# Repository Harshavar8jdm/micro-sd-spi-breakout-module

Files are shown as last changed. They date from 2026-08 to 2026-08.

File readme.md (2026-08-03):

# 3.3V MicroSD Card SPI Breakout Board

A compact, high-performance, 2-layer **MicroSD Card Breakout Board** designed in KiCad for embedded microcontrollers using the **SPI (Serial Peripheral Interface)** bus.

Designed specifically for 3.3V native logic ecosystems (STM32, ESP32, RP2040, SAMD, Nordic, etc.), this module provides clean power decoupling, signal pull-ups, and a low-EMI ground plane layout.

---

## Board Renders

| Top View | Bottom View |
| :---: | :---: |
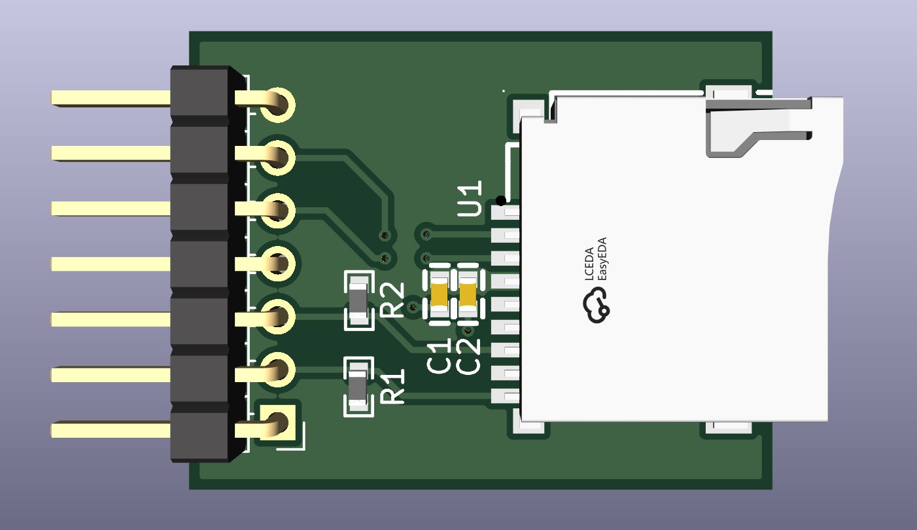
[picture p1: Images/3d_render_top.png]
3D Top Render
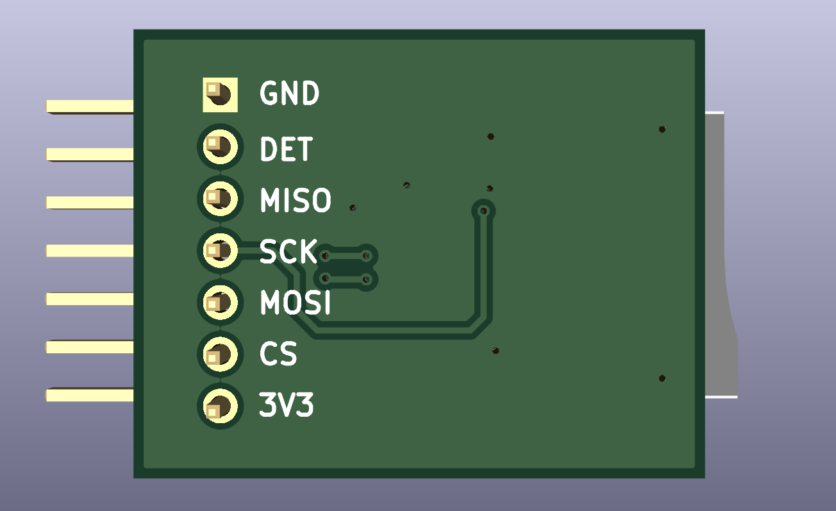
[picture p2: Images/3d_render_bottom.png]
3D Bottom Render
|  |  |

---

## Key Features

* **Native 3.3V Operation:** Designed without slow active/passive level shifters, maximizing SPI bus speeds (up to 25 MHz) with zero signal propagation delay.
* **Transient Power Decoupling:** Dedicated 10 uF bulk ceramic cap (C1) and 100 nF high-frequency ceramic cap (C2) positioned directly adjacent to the SD socket's VDD pin (Pin 4) to handle flash memory write current spikes (up to 200 mA).
* **Bus Stability:** Integrated 10k Ohm pull-up resistors on signal lines to prevent floating inputs and accidental bus writes during microcontroller startup/reset.
* **Card Detection:** Mechanically broken-out Card Detect (CD_DET) line to trigger hardware interrupts on card insertion/removal.
* **Optimized 2-Layer Signal Integrity:** Signal routing optimized for continuous return paths over an unbroken bottom Ground plane, minimizing EMI and clock ringing.
* **Standard 2.54mm Header:** 1x7 pin header footprint for breadboard prototyping or jumper wiring.

---

## Schematic & Layout

### Schematic
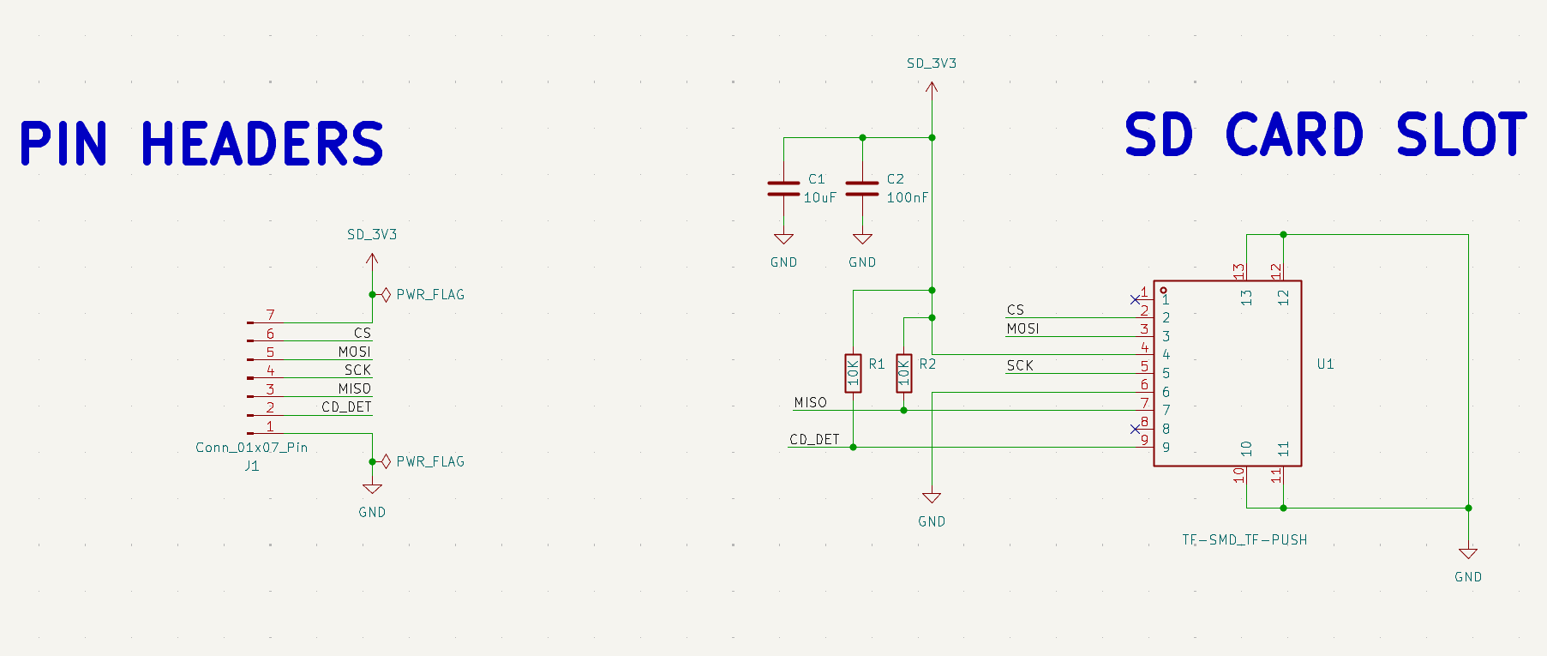
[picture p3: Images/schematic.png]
Schematic


### PCB Layout
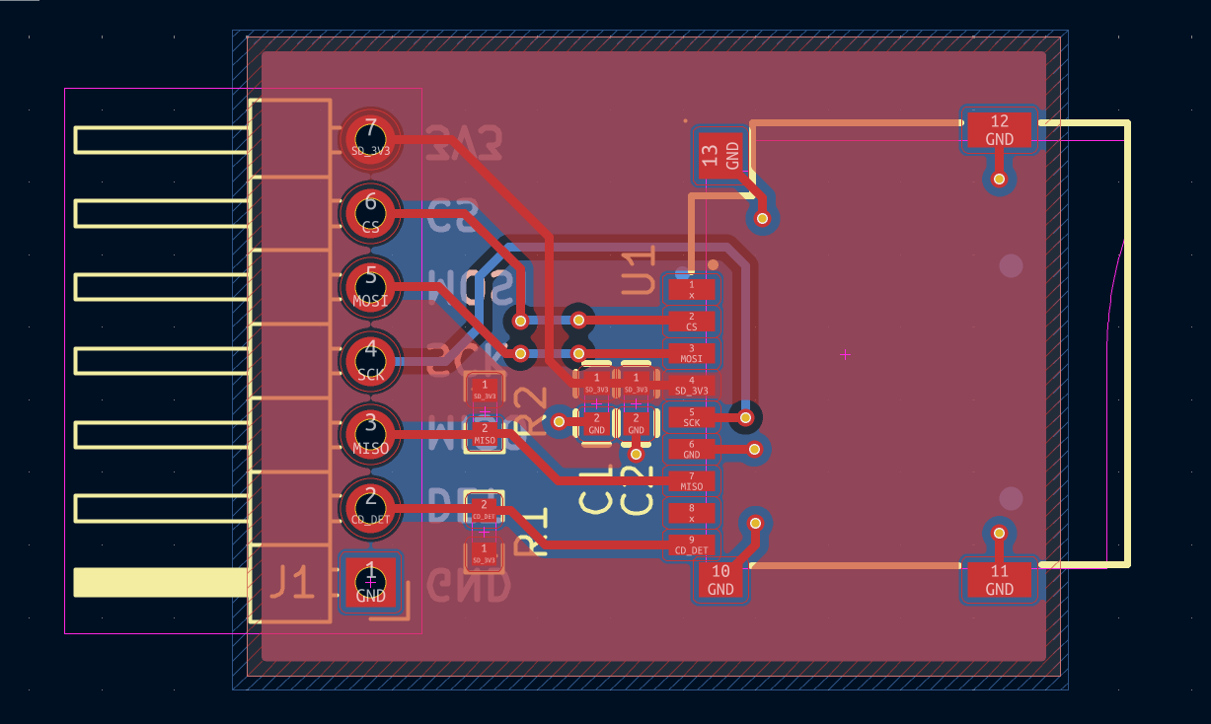
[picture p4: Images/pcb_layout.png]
PCB Layout


---

## Bill of Materials (BOM)

| Reference | Quantity | Value / Part | Footprint / Package | Description |
| :--- | :---: | :--- | :--- | :--- |
| **U1** | 1 | `TF_SMD_TF-PUSH` | MicroSD Push-Push Connector | Surface Mount TF/MicroSD Socket |
| **J1** | 1 | `Conn_01x07_Pin` | PinHeader 1x07, P2.54mm, Vertical | 0.1 inch Pitch Male Pin Header |
| **C1** | 1 | 10 uF | Ceramic Cap, 0805 | Bulk Power Decoupling |
| **C2** | 1 | 100 nF | Ceramic Cap, 0603 | High-Frequency Decoupling |
| **R1, R2** | 2 | 10k Ohm | Resistor, 0603 | Signal Pull-Up Resistors |

---

## Software Integration & Bring-Up Guide

### 1. SPI Clock Speed Stages
When writing software/drivers for SD cards via SPI:
1. **Initialization Phase (100 kHz - 400 kHz):** The SD Card specification requires initial setup (`CMD0`, `CMD8`, `ACMD41`) to be executed at a slow clock speed (<400 kHz) while the card initializes its internal state machine into SPI mode.
2. **Operational Phase (10 MHz - 25 MHz):** Once initialized into SPI mode, increase your MCU's SPI peripheral clock frequency up to **20-25 MHz** for high-throughput block read/write transfers.

### 2. Microcontroller Compatibility Notice
* **Native 3.3V MCUs (STM32, ESP32, RP2040, SAMD):** Connect directly to header pins.
* **5V MCUs (e.g., Classic Arduino Uno R3):** Require external active level shifters (like 74LVC125A) on `SCK`, `MOSI`, and `CS` lines to prevent over-voltage damage to the SD card.

---

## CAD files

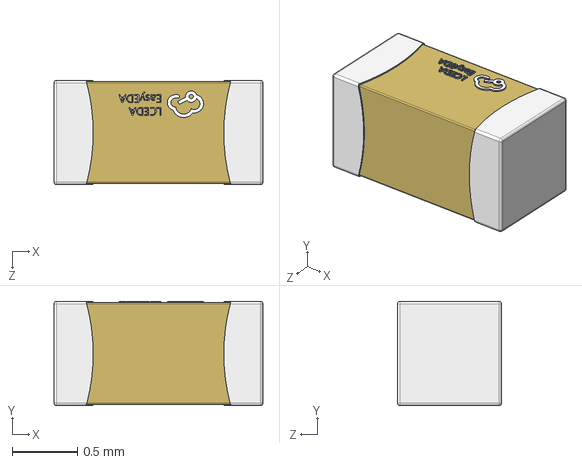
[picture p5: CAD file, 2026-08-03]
ext-libs/C0603_CC0603JRX7R9BB104_C91183/C0603_CC0603JRX7R9BB104_C91183.step
1.60 x 0.8 x 0.8 mm

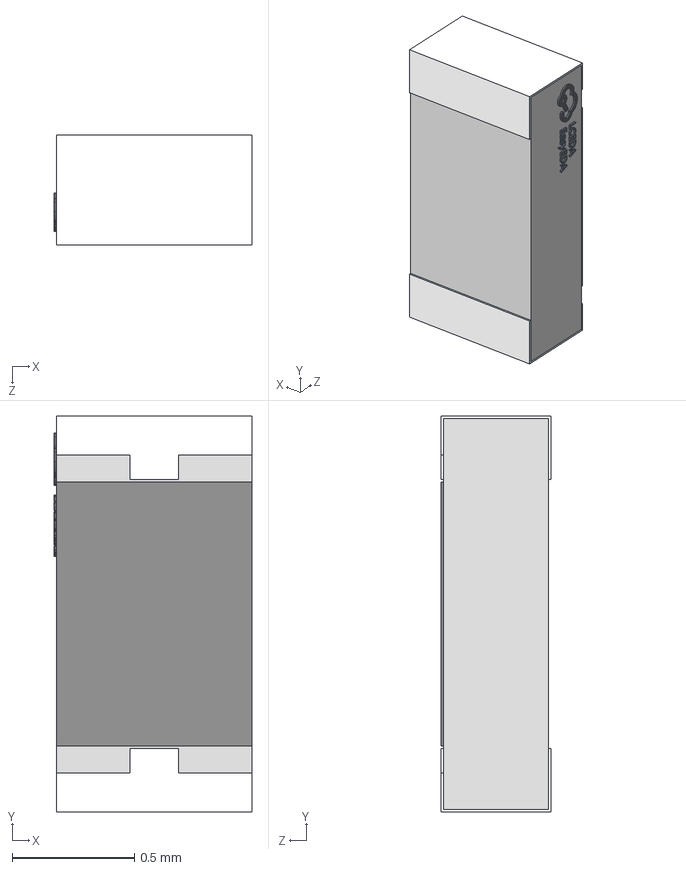
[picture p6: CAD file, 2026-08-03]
ext-libs/R0603_FRC0603F1001TS_C2907002/R0603_FRC0603F1001TS_C2907002.step
0.81 x 1.62 x 0.45 mm

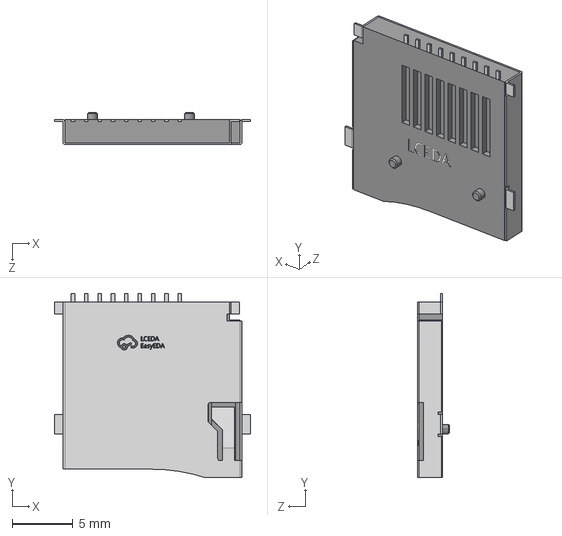
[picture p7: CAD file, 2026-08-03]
ext-libs/TF-SMD_TF-PUSH_TF_PUSH_C393941/TF-SMD_TF-PUSH_TF_PUSH_C393941.step
16.1 x 15.2 x 2.65 mm

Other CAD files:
ext-libs/C0603_CC0603JRX7R9BB104_C91183/C0603_CC0603JRX7R9BB104_C91183.obj
ext-libs/C0603_CL10A106KP8NNNC_C19702/C0603_CL10A106KP8NNNC_C19702.obj
ext-libs/R0603_FRC0603F1001TS_C2907002/R0603_FRC0603F1001TS_C2907002.obj
ext-libs/TF-SMD_TF-PUSH_TF_PUSH_C393941/TF-SMD_TF-PUSH_TF_PUSH_C393941.obj

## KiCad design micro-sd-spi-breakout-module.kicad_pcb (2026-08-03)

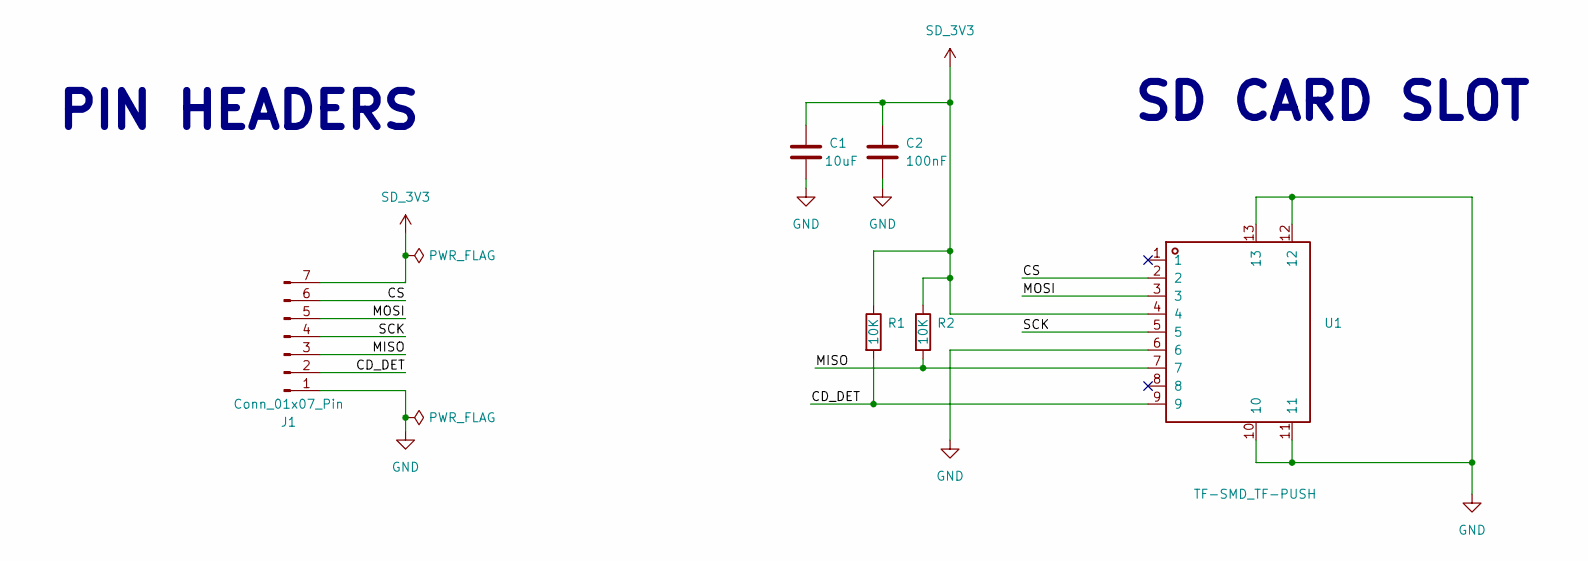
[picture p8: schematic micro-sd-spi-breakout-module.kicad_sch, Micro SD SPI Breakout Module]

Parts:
C1: 10uF; C0603_CL10A106KP8NNNC_C19702
C2: 100nF; C0603_CC0603JRX7R9BB104_C91183
J1: Conn_01x07_Pin; PinHeader_1x07_P2.54mm_Horizontal
R1, R2: 10K; R0603_FRC0603F1001TS_C2907002
U1: TF-SMD_TF-PUSH; TF-SMD_TF-PUSH_TF_PUSH_C393941

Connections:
/CD_DET: J1.2, R1.2, U1.9
/CS: J1.6, U1.2
/MISO: J1.3, R2.2, U1.7
/MOSI: J1.5, U1.3
/SCK: J1.4, U1.5
GND: C1.2, C2.2, J1.1, U1.6, U1.10, U1.11, U1.12, U1.13
SD_3V3: C1.1, C2.1, J1.7, R1.1, R2.1, U1.4

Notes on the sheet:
PIN HEADERS
SD CARD SLOT

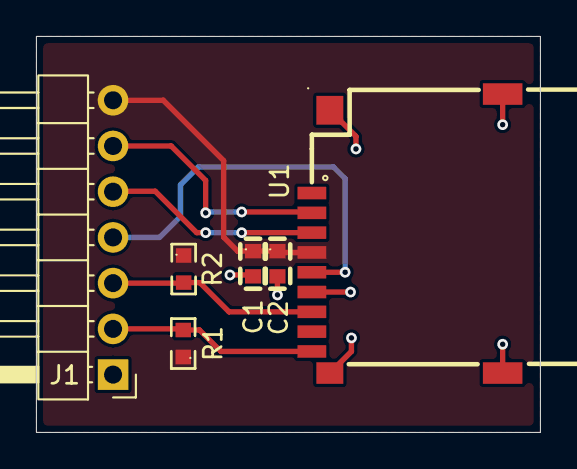
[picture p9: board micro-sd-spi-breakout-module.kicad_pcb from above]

Board: 2 copper layers, 28.0 x 22.0 mm, 6 parts (0 on the bottom side), 7 nets.
